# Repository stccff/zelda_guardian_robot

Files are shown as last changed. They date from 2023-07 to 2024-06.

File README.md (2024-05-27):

# 塞尔达传说旷野之息守护者模型项目

## 项目介绍

本项目致力于复刻《塞尔达传说：旷野之息》中的守护者模型。项目包含了守护者的SolidWorks模型、硬件PCB设计以及基于ESP32-S3的软件部分。

## 项目展示

- **图片**
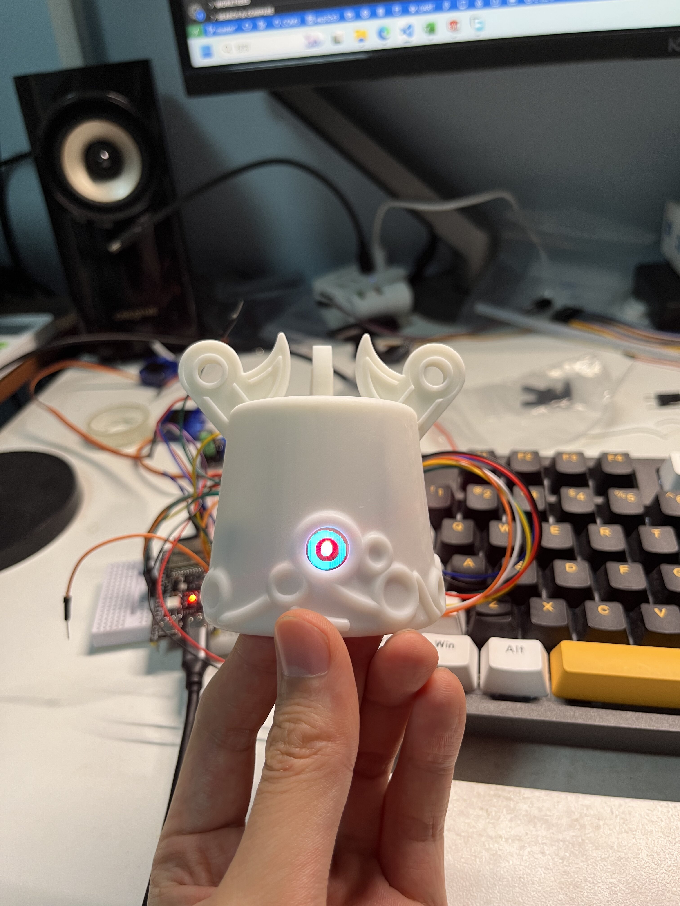
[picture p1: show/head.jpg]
头部测试
  - 
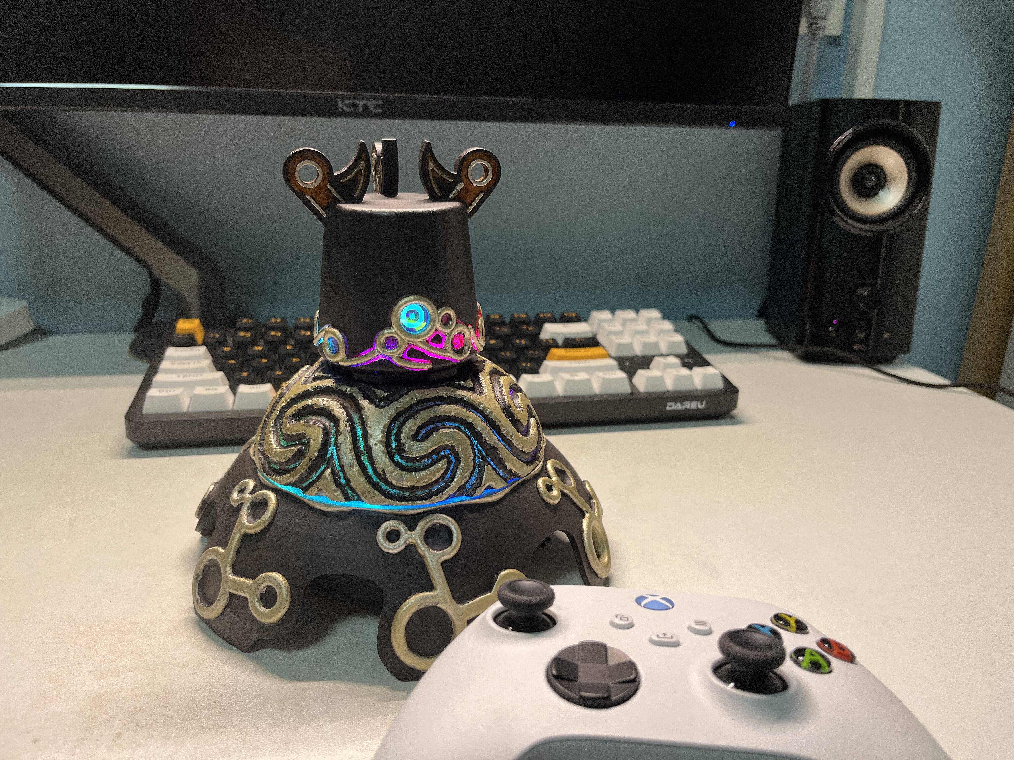
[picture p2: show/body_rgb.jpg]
RGB效果
  - 
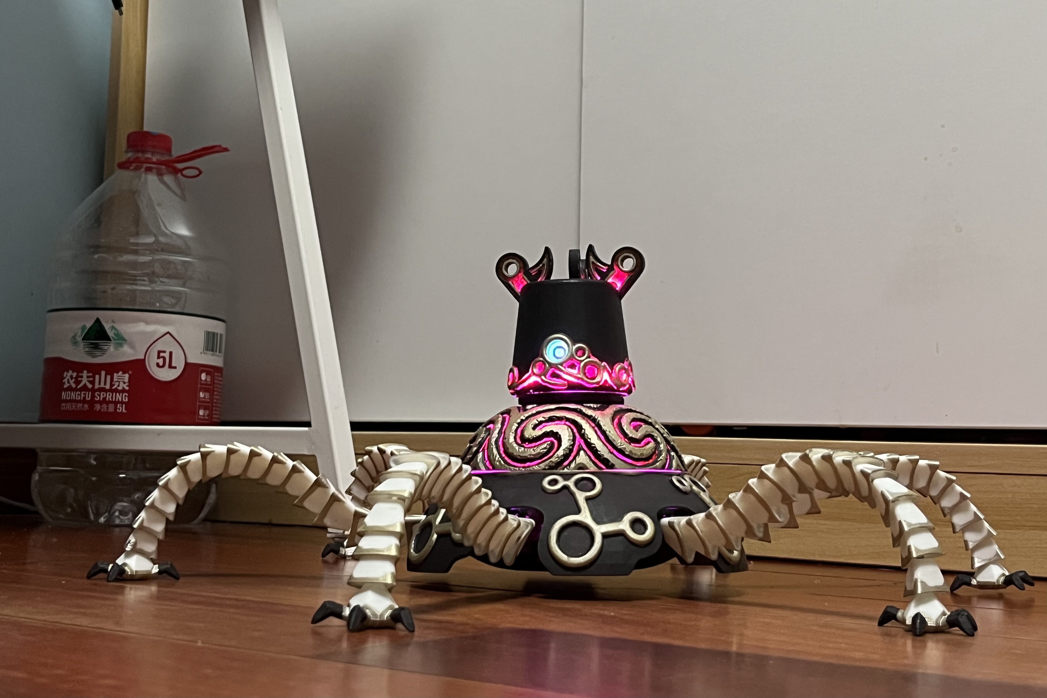
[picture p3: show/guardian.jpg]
整体效果
  - 
- **视频**
  - B站链接：https://www.bilibili.com/video/BV1vh4y1A7ve/?share_source=copy_web&vd_source=ff8870a89e973cca407edad87d57f622
  - 油管链接：https://youtu.be/EcbjQE96Pl4?si=KqaRee9nlnVQqD4i

## 项目内容

- **SolidWorks模型**
  - 守护者3D模型设计
  - 可打印的STL文件
- **硬件PCB设计**
  - 电路图和PCB布局
  - 元件清单
  - 制造文件
- **软件部分（ESP32-S3）**
  - 嵌入式C代码
  - 功能实现说明

## 使用说明

1. **获取SolidWorks模型**
   - 下载STL文件
   - 使用3D打印机打印模型
2. **硬件PCB制作**
   - 根据提供的文件制作PCB
   - 元件焊接与测试
3. **软件编程与调试**
   - 下载vs code或其他兼容的开发环境
   - 编译并上传固件到ESP32-S3模块
   - 调试与功能测试

## 开发环境

- **SolidWorks** (用于编辑和查看3D模型)
- **VS code** (用于编写和上传ESP32-S3代码)
- **推荐的PCB设计软件** (立创eda)

## 参与贡献

欢迎对《塞尔达传说：旷野之息》守护者模型感兴趣的开发者参与项目！请通过GitHub的Pull Request功能提交您的贡献。
也可以加入我的qq交流群：971609269

## 许可证

本项目采用[MIT许可证](https://opensource.org/licenses/MIT)。

## 联系方式

如需报告问题或提出建议，请通过GitHub的Issue跟踪系统告知。

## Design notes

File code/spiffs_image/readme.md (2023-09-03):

注意事项：
使用AU导出音频时，不能勾选"包含标记和其他元素"

guardian_beamsightlocking
	loop start: 5936 samples (0:00.124 seconds)
	loop end: 17498 samples (0:00.365 seconds)

guardian_beamsightsearch
	loop start: 0 samples (0:00.000 seconds)
	loop end: 5115 samples (0:00.107 seconds)

SE_Guardian_ActiveFastLoop
	loop start: 23100 samples (0:00.481 seconds)
	loop end: 116618 samples (0:02.430 seconds)

SE_Guardian_SlideLoop
	loop start: 31206 samples (0:00.650 seconds)
	loop end: 96924 samples (0:02.019 seconds)

Guardian_Active_Move
	loop start: 0 samples (0:00.000 seconds)
	loop end: 246537 samples (0:05.136 seconds)

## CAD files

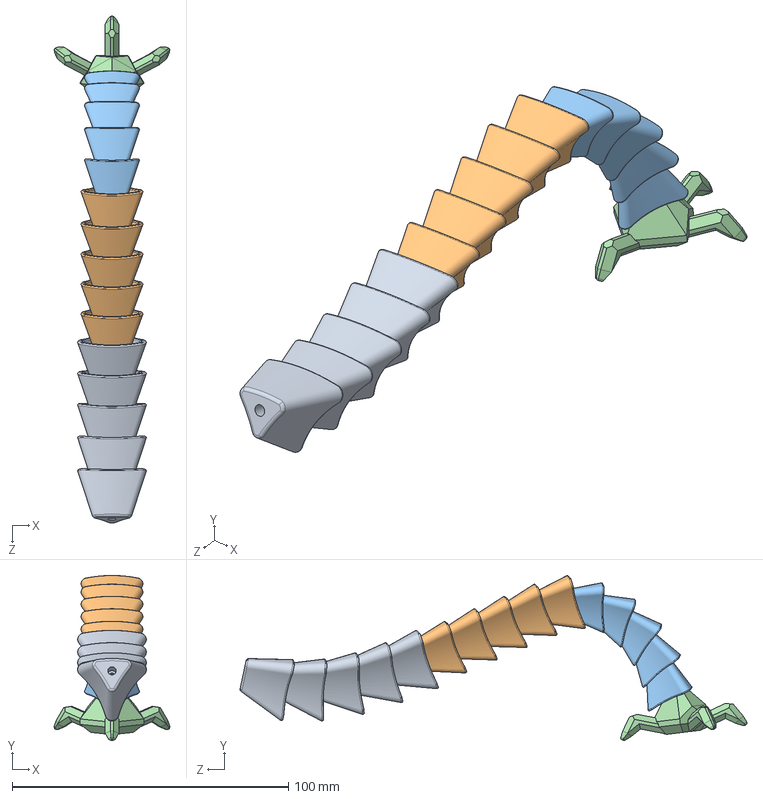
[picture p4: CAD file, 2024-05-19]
model/leg.SLDASM
41.9 x 59.8 x 183.7 mm
leg0 x 5
leg1 x 5
leg2 x 5
foot

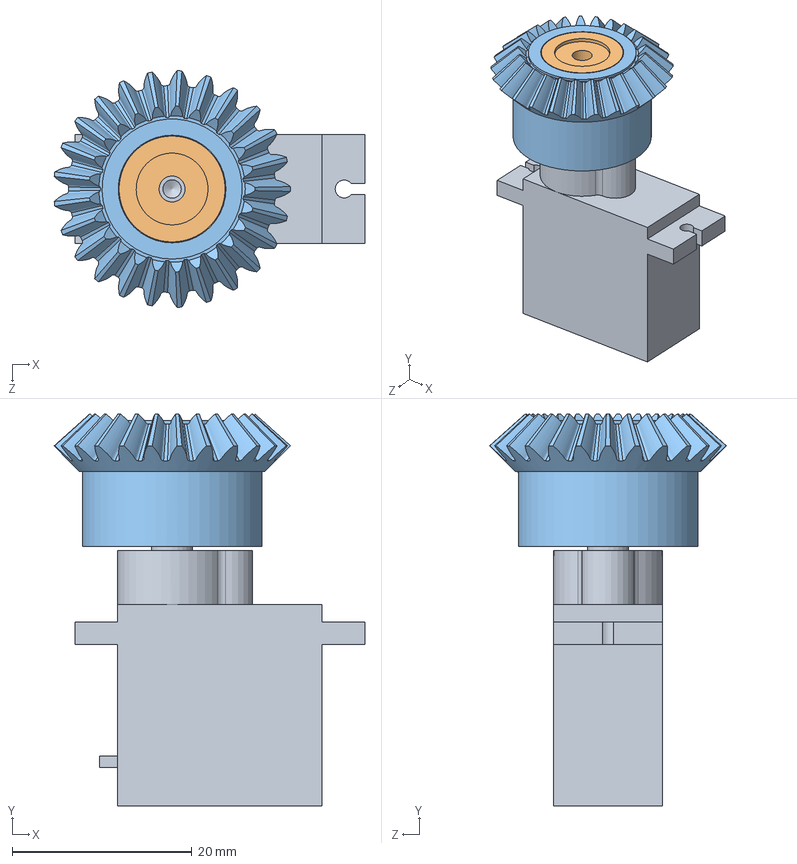
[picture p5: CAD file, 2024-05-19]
model/servo&gear.SLDASM
34.6 x 43.7 x 26.4 mm
servo_motor(MG90D)
servo&gear_connector
bevel_gear_25x1x12

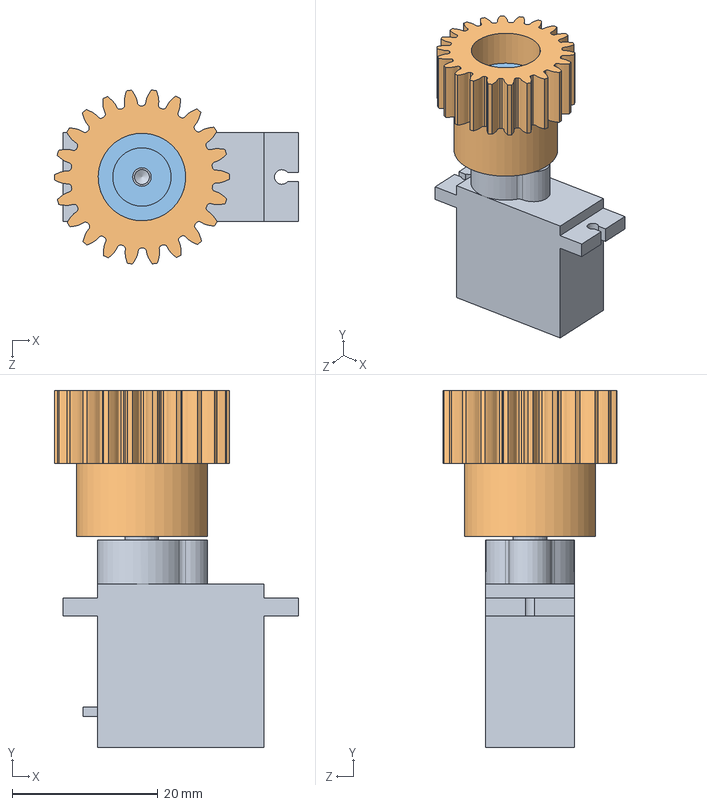
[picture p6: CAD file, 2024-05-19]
model/servo&gear2.SLDASM
33.5 x 48.9 x 23.9 mm
servo_motor(MG90D)
spur_gear_22x1_12
servo&gear_connector

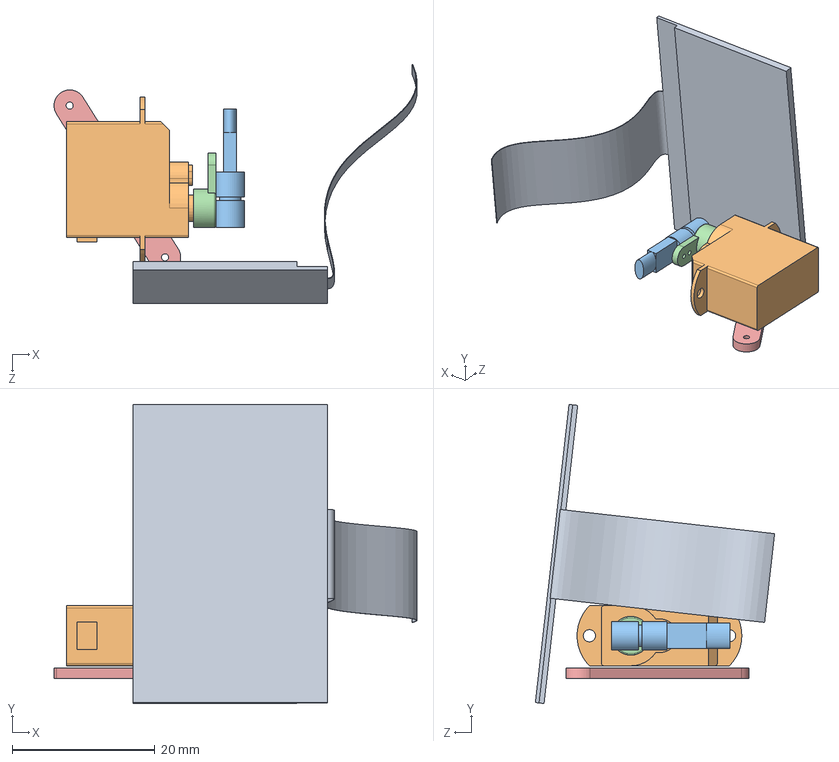
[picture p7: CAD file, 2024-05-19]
model/guardian_head.SLDASM
50.9 x 41.9 x 33.5 mm
oled_transparent
servo_motor(mini)
laser
mini_handle
servo_motor_holder2

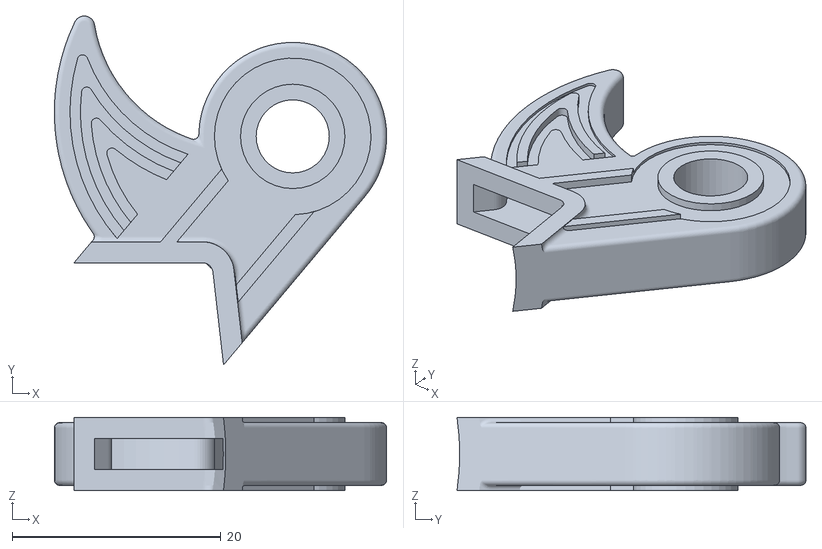
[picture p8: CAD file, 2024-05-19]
model/testchip/head_corner.STL
31.8 x 33.4 x 7.00

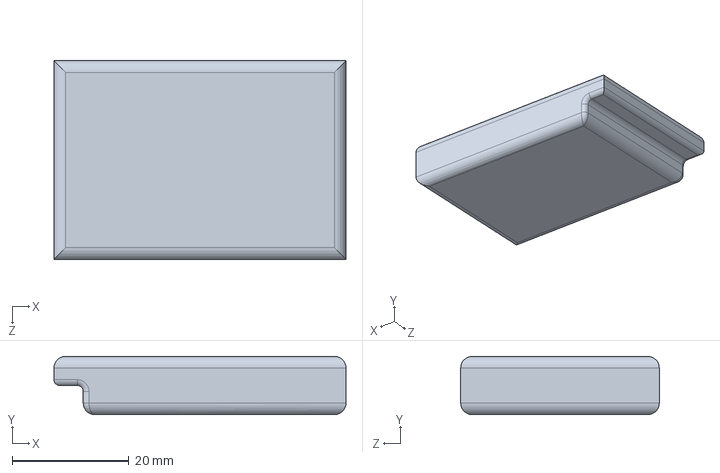
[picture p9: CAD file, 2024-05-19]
model/Li-ion_103450.SLDPRT
50.0 x 10.0 x 34.0 mm

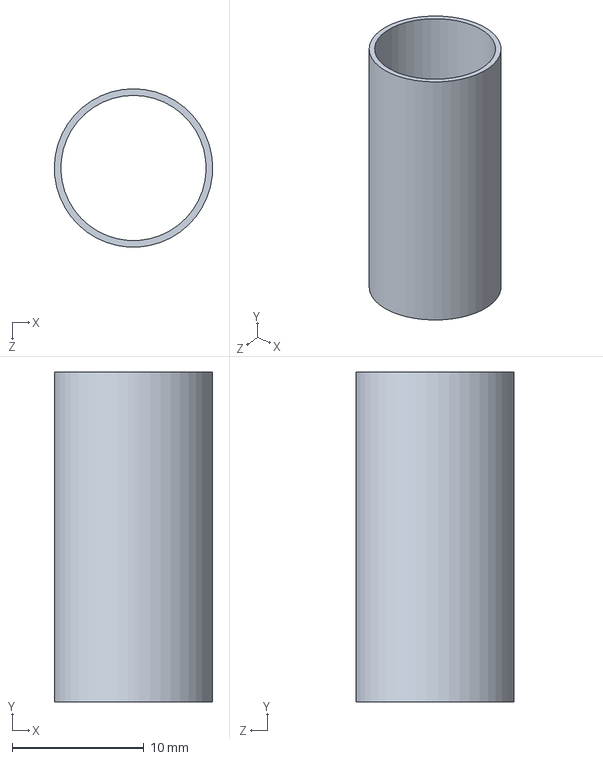
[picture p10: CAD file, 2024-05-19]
model/shaft_12x0.5.SLDPRT
12.0 x 25.0 x 12.0 mm

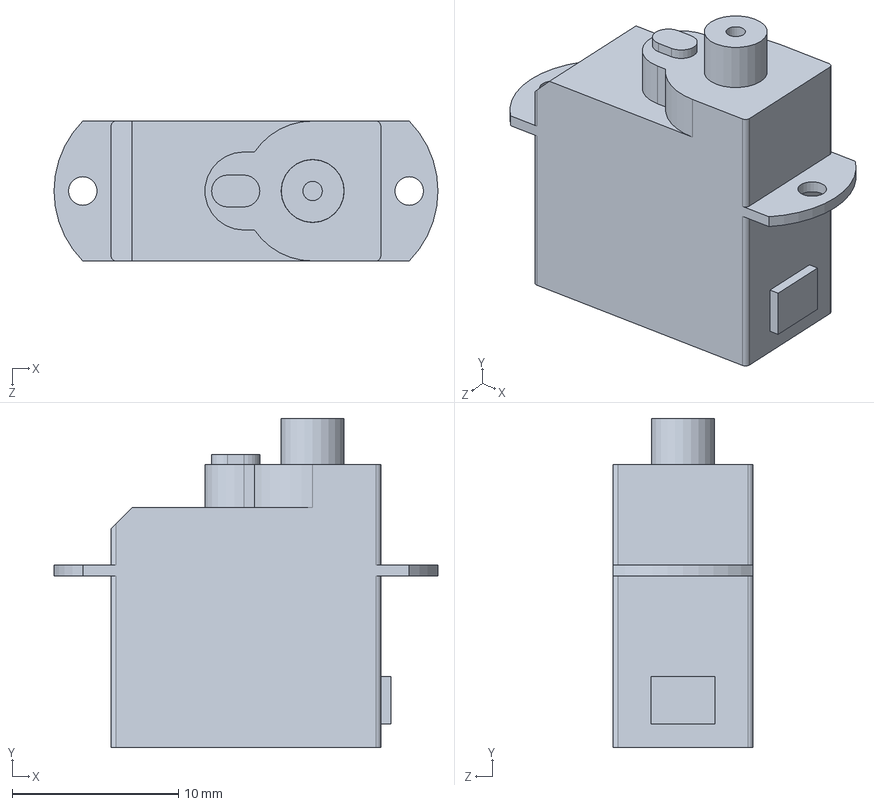
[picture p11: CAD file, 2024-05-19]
model/servo_motor(mini).SLDPRT
23.1 x 19.8 x 8.42 mm

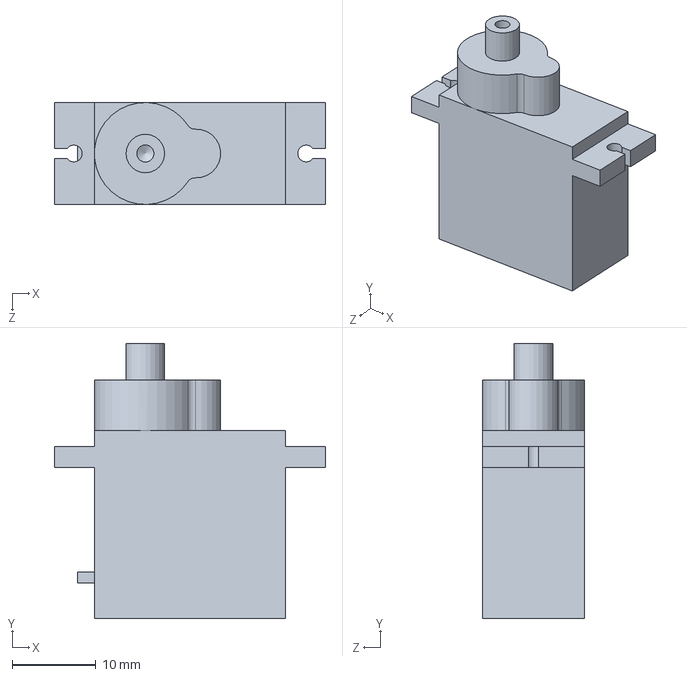
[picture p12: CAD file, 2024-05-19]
model/servo_motor(MG90D).SLDPRT
32.3 x 32.8 x 12.2 mm

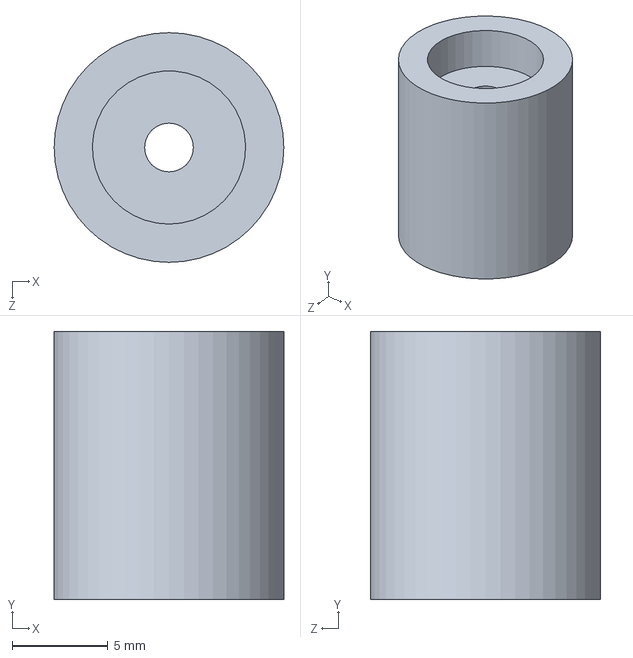
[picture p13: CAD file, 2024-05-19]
model/servo&gear_connector.SLDPRT
12.0 x 14.0 x 12.0 mm

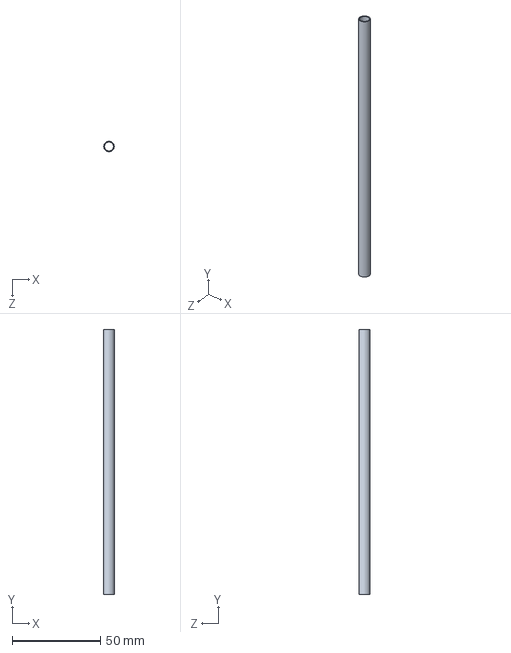
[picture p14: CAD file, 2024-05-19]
model/shaft_6x0.5.SLDPRT
6.00 x 150.0 x 6.00 mm

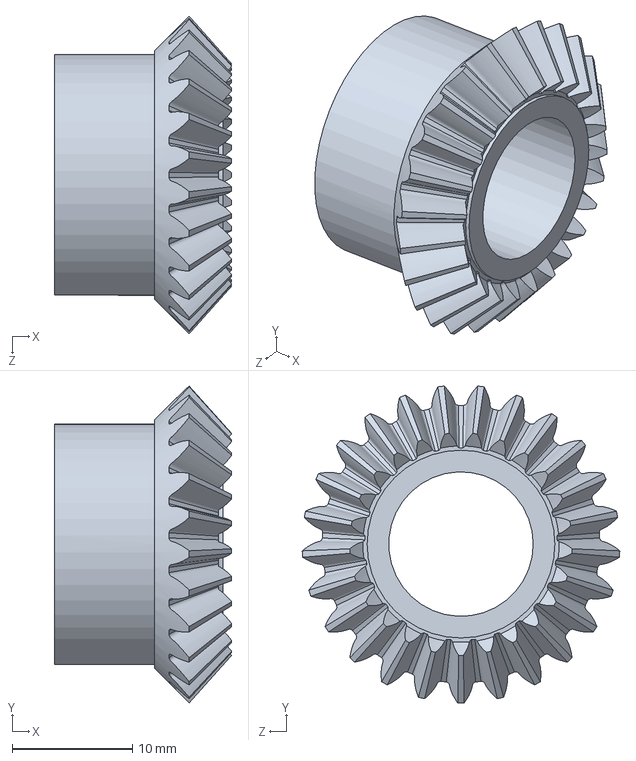
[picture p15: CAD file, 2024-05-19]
model/bevel_gear_25x1x12.SLDPRT
14.7 x 26.3 x 26.4 mm

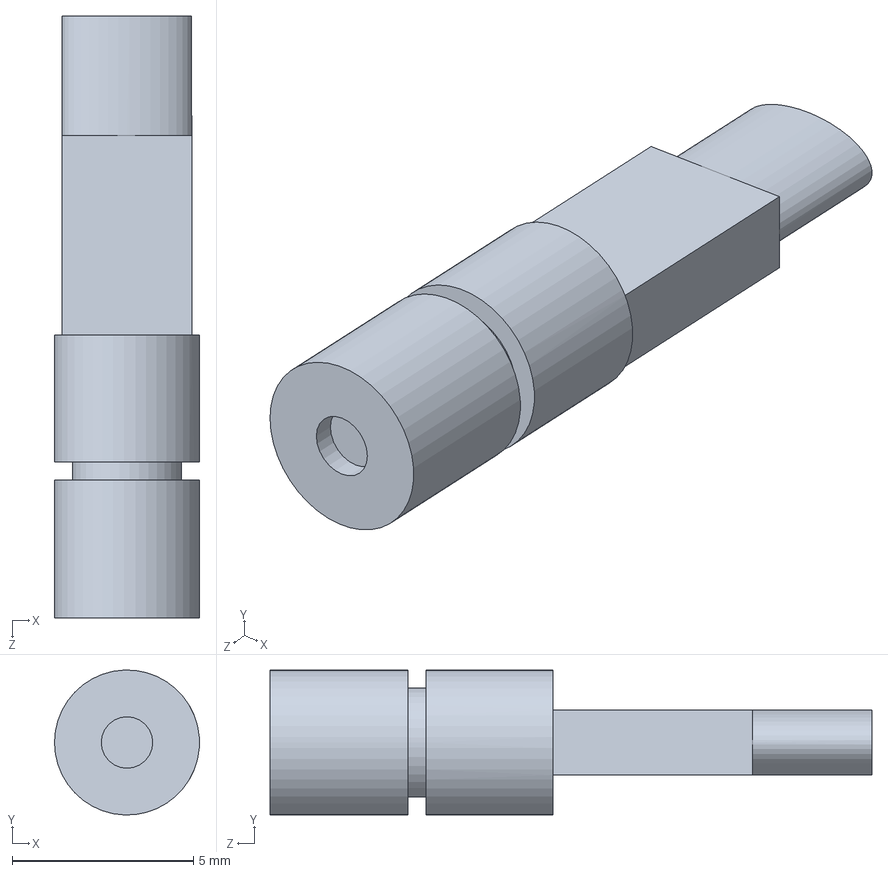
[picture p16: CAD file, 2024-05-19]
model/laser.SLDPRT
4.00 x 4.00 x 16.6 mm

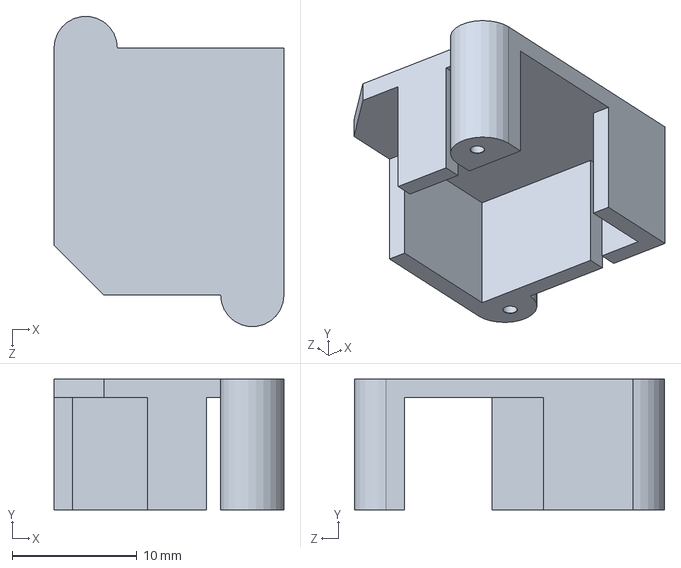
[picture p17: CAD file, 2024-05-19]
model/servo_motor_holder.SLDPRT
18.4 x 10.5 x 24.9 mm

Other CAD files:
model/bottom.SLDPRT
model/foot.SLDPRT
model/oled_transparent.SLDPRT
model/decorative_gear.SLDPRT
model/18650_with_protector.SLDPRT
model/bevel_gear_25x1x6.SLDPRT
model/bevel_gear_25x1x8.SLDPRT
model/head_connector.SLDPRT
model/legacy/handle2(MG90D).SLDPRT
model/legacy/spur_gear_20×1.SLDPRT
model/mini_handle.SLDPRT
model/servo_motor(SG90).SLDPRT
model/servo_motor_holder2.SLDPRT
model/shaft_10x0.8(2).SLDPRT
model/shaft_10x0.8.SLDPRT
model/shaft_12x0.5(2).SLDPRT
model/shaft_8x0.5.SLDPRT
model/speaker.SLDPRT
model/spur_gear_22x1_10.1.SLDPRT
model/spur_gear_22x1_12.SLDPRT

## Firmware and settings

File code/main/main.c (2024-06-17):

/*
 * SPDX-FileCopyrightText: 2021 Espressif Systems (Shanghai) CO LTD
 *
 * SPDX-License-Identifier: Unlicense OR CC0-1.0
 */

#include <stdio.h>
#include <stdlib.h>
#include <string.h>
#include "freertos/FreeRTOS.h"
#include "freertos/task.h"
#include "freertos/event_groups.h"
#include "esp_system.h"
#include "esp_log.h"
#include "hid_host_gamepad.h"
#include "oled_main.h"
#include "servo_control.h"
#include "i2s_std_sound.h"
#include "pwr_ctrl.h"
#include "rgb_ctrl.h"
#include "status_machine.h"

static portMUX_TYPE g_spinLock = portMUX_INITIALIZER_UNLOCKED;

/*
 vTaskGetRunTimeStats() 使用
 注意:
 使用 vTaskGetRunTimeStats() 前需使能:
 make menuconfig -> Component config -> FreeRTOS -> configUSE_TRACE_FACILITY
 make menuconfig -> Component config -> FreeRTOS -> Enable FreeRTOS trace facility -> configUSE_STATS_FORMATTING_FUNCTIONS
 make menuconfig -> Component config -> FreeRTOS -> Enable display of xCorelD in vlaskList
 make menuconfig -> Component config -> FreeRTOS -> configGENERATE_RUN_TIME_STATS
 通过上面配置，等同于使能 FreeRTOSConfig.h 中如下三个宏:
 configGENERATE_RUN_TIME_STATS，configUSE_STATS_FORMATTING_FUNCTIONS 和 configSUPPORT_DYNAMIC_ALLOCATION
 */
void print_task_info(char *buff)
{
    /* 打印当前任务列表 */
    vTaskList(buff);
    printf("task\t\tstate\tprio\tstack\ttid\tcore\n");
    printf("%s\n", buff);
    /* 打印任务运行信息 */
    vTaskGetRunTimeStats(buff);
    printf("task_name\trun_cnt\t\tusage\n");
    printf("%s\n", buff);
}

static bool is_demo_mod(void)
{
    volatile const struct XboxData *xbox = get_xbox_pad_data();
    if (sm_get_active_mod() != SM_DEMO || xbox->bnt2.btnStart == 1) {
        vTaskDelay(200 / portTICK_PERIOD_MS);
        sm_set_active_mod(SM_NORMAL);
        struct XboxData virXbox = {
            .joyLx = 0xffff / 2,
            .joyRx = 0xffff / 2,
            .joyRy = 0xffff / 2,
            .trigRT = 0,
        };
        set_xbox_pad_data_virtual(&virXbox);
        oled_set_display(OLED_OFF);
        vTaskDelay(200 / portTICK_PERIOD_MS);
        return false;
    }
    return true;
}

static bool demo_delay_and_check(uint32_t ms)
{
    bool is_demo;
    for (uint32_t i = 0; (i < ms / 20) && (is_demo = is_demo_mod() == true); i++) {
        vTaskDelay(20 / portTICK_PERIOD_MS);
    }

    return is_demo;
}

/**
 * @brief demo sequence
 * 
 */
static void do_demo_sequence(void)
{
    /* sleep */
    sm_set_light_status(SM_NO_LIGHT);
    if (demo_delay_and_check(4000) == false) {
        return;
    }
    
    /* eye on */
    oled_set_display(OLED_CIRCLE);
    sm_set_light_status(SM_LIGHT_SCREEN);
    sound_play_eyeon(true);
    if (demo_delay_and_check(3000) == false) {
        return;
    }

    /* blue */
    sm_set_light_status(SM_LIGHT_SCREEN_BLUE);
    if (demo_delay_and_check(3000) == false) {
        return;
    }

    /* randon move */
    struct XboxData virXbox = {
        .joyLx = 0xffff / 2,
        .joyRx = 0xffff / 2,
        .joyRy = 0xffff / 2,
        .trigRT = 0,
    };
    virXbox.joyLx = XBOX_JOYSTICK_MAX / 2 - XBOX_JOYSTICK_MAX / 20 * 9;
    virXbox.joyRx = XBOX_JOYSTICK_MAX / 2 + XBOX_JOYSTICK_MAX / 20 * 9;
    set_xbox_pad_data_virtual(&virXbox);
    if (demo_delay_and_check(500) == false) {
        return;
    }

    virXbox.joyLx = XBOX_JOYSTICK_MAX / 2 + XBOX_JOYSTICK_MAX / 20 * 9;
    virXbox.joyRx = XBOX_JOYSTICK_MAX / 2 - XBOX_JOYSTICK_MAX / 20 * 9;
    set_xbox_pad_data_virtual(&virXbox);
    if (demo_delay_and_check(1000) == false) {
        return;
    }

    virXbox.joyLx = XBOX_JOYSTICK_MAX / 2 - XBOX_JOYSTICK_MAX / 20 * 9;
    virXbox.joyRx = XBOX_JOYSTICK_MAX / 2 + XBOX_JOYSTICK_MAX / 20 * 9;
    set_xbox_pad_data_virtual(&virXbox);
    if (demo_delay_and_check(1000) == false) {
        return;
    }

    virXbox.joyLx = XBOX_JOYSTICK_MAX / 2 + XBOX_JOYSTICK_MAX / 20 * 9;
    virXbox.joyRx = XBOX_JOYSTICK_MAX / 2 - XBOX_JOYSTICK_MAX / 20 * 9;
    set_xbox_pad_data_virtual(&virXbox);
    if (demo_delay_and_check(500) == false) {
        return;
    }
    
    // resume
    virXbox.joyLx = XBOX_JOYSTICK_MAX / 2;
    virXbox.joyRx = XBOX_JOYSTICK_MAX / 2;
    set_xbox_pad_data_virtual(&virXbox);

    /* attach */
    sm_set_light_status(SM_LIGHT_SCREEN_RED);
    if (demo_delay_and_check(1000) == false) {
        return;
    }
    virXbox.trigRT = XBOX_TRIGGER_MAX;
    set_xbox_pad_data_virtual(&virXbox);

    virXbox.joyRy = XBOX_JOYSTICK_MAX / 2 - XBOX_JOYSTICK_MAX / 20 * 6;
    set_xbox_pad_data_virtual(&virXbox);
    if (demo_delay_and_check(200) == false) {
        return;
    }

    virXbox.joyRy = XBOX_JOYSTICK_MAX / 2 + XBOX_JOYSTICK_MAX / 20 * 6;
    set_xbox_pad_data_virtual(&virXbox);
    if (demo_delay_and_check(400) == false) {
        return;
    }

    virXbox.joyRy = XBOX_JOYSTICK_MAX / 2 - XBOX_JOYSTICK_MAX / 20 * 6;
    set_xbox_pad_data_virtual(&virXbox);
    if (demo_delay_and_check(400) == false) {
        return;
    }

    virXbox.joyRy = XBOX_JOYSTICK_MAX / 2 + XBOX_JOYSTICK_MAX / 20 * 6;
    set_xbox_pad_data_virtual(&virXbox);
    if (demo_delay_and_check(400) == false) {
        return;
    }

    virXbox.joyRy = XBOX_JOYSTICK_MAX / 2 - XBOX_JOYSTICK_MAX / 20 * 6;
    set_xbox_pad_data_virtual(&virXbox);
    if (demo_delay_and_check(200) == false) {
        return;
    }

    // resume
    virXbox.joyRy = XBOX_JOYSTICK_MAX / 2;
    set_xbox_pad_data_virtual(&virXbox);

    if (demo_delay_and_check(4000) == false) {
        return;
    }
    
    virXbox.trigRT = 0;
    set_xbox_pad_data_virtual(&virXbox);
    if (demo_delay_and_check(5000) == false) {
        return;
    }

    sm_set_light_status(SM_LIGHT_SCREEN_BLUE);
    if (demo_delay_and_check(10000) == false) {
        return;
    }
}

/**
 * @brief 主函数
 * 
 */
void app_main(void)
{
    /* init process*/
    taskENTER_CRITICAL(&g_spinLock);
    status_machine_init();
    taskEXIT_CRITICAL(&g_spinLock);

    pwr_ctrl_init();    // 2
    servo_init();       // 3
    sound_init();       // 7/6
    oled_main();        // 10   周期刷新数据
    argb_init();        // 12   周期刷新数据
    hid_host_init();    // 15

    char *buff = (char *)malloc(1024);
    print_task_info(buff);

    while (1) {
        /* print task info */
        volatile const struct XboxData *xbox = get_xbox_pad_data();
        if (xbox->bnt3.share == 1) {
            print_task_info(buff);
        }

        /* demo mod detecte */
        if (xbox->bnt2.btnStart == 1) {
            vTaskDelay(300 / portTICK_PERIOD_MS);
            sm_set_active_mod(SM_DEMO);
        }

        /* demo auto play */
        while (sm_get_active_mod() == SM_DEMO) {
            do_demo_sequence();
        }

        vTaskDelay(100 / portTICK_PERIOD_MS);
    }
    free(buff);

    vTaskDelete(NULL);
}

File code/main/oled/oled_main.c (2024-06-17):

/* SPI Master example

   This example code is in the Public Domain (or CC0 licensed, at your option.)

   Unless required by applicable law or agreed to in writing, this
   software is distributed on an "AS IS" BASIS, WITHOUT WARRANTIES OR
   CONDITIONS OF ANY KIND, either express or implied.
*/
#include <stdio.h>
#include <stdlib.h>
#include <string.h>
#include <inttypes.h>
#include "freertos/FreeRTOS.h"
#include "freertos/task.h"
#include "esp_system.h"
#include "driver/spi_master.h"
#include "driver/gpio.h"
#include "oled_drv.h"
#include "driver/uart.h"
#include "picture.h"
#include <math.h>
#include "oled_main.h"
#include "status_machine.h"
#include "esp_log.h"
#include "pwr_ctrl.h"
#include "i2s_std_sound.h"
#include "common_func.h"

/* 宏定义 */
#define TEST_TASK_STACK_SIZE    (10 * 1024)

#define SCREEN_WIDTH    (128)   // 屏幕长
#define SCREEN_HEIGHT   (64)    // 屏幕高
#define SCREEN_PAGE_NUM (8)     // 屏幕页数

#define CIRCLE_WIDTH    (48)    // 画圆的buffer长
#define CIRCLE_HEIGHT   (48)    // 画圆的buffer宽
#define CIRCLE_x        (21)    // 圆心在buff中的x坐标
#define CIRCLE_y        (24)    // 圆心在buff中的y坐标
#define MASK_R          (21)    // 外部遮罩半径

/* 结构体定义 */
struct OledMonoBuff {
    int width;
    int height;
    uint8_t *buff;  // buff指针
};

/* 全局变量 */
static const char *TAG = "OLED";



static double square(double x)
{
	return x * x;
}

/**
 * @brief 设置一个Byte中对应的bit像素点
 * 
 * @param pixel8 一个子节对应的8个像素
 * @param index 设置的像素索引
 * @param val 像素颜色（黑/白）
 */
static void set_bit(unsigned char *pixel8, int index, int val)
{
    if (val == 0) {
        *pixel8 &= ~((unsigned char)(1 << index));
    } else {
        *pixel8 |= (unsigned char)(1 << index);
    }
}

/**
 * @brief 设置一个绘制buff中的一个像素值
 * 
 * @param buff 屏幕buff结构体指针
 * @param row 设置的行数
 * @param col 设置的列数
 * @param val 像素颜色（黑/白）
 */
static void oled12864_set_pixel(struct OledMonoBuff *buff, int row, int col, int val)
{
    if ((row >= buff->height) || (col >= buff->width)) {
        return;
    }
    
    int page = col / 8;
    int index = col % 8;
    set_bit(&buff->buff[page * buff->width + row], index, val);
}

/**
 * @brief 绘制一个环形，存放在指定buff中
 * 
 * @param buff 屏幕buff结构体指针
 * @param x 圆心横坐标
 * @param y 圆心纵坐标
 * @param r1 内径
 * @param r2 外径
 * @param val 像素颜色（黑/白）
 */
static void draw_circle(struct OledMonoBuff *buff, int x, int y, int r1, int r2, int val)
{
    for (int i = 0; i < buff->height; i++) {
        for (int j = 0; j < buff->width; j++) {
			double len2 = square(i - x) + square(j - y);
            if ((len2 >= r1 * r1) && (len2 < r2 * r2) && (len2 <= MASK_R * MASK_R)) {
                oled12864_set_pixel(buff, i, j, val);
            }
        }
    }
}

/**
 * @brief 绘制多重环形图案，并写入指定的buff中
 * 
 * @param buff 屏幕buff结构体指针
 * @param outerR 最内部环形外径
 * @param width 环形宽度（内外径差）
 * @param interval 相邻环形半径
 * @param val 像素颜色（黑/白）
 */
static void draw_multi_circle(struct OledMonoBuff *buff, int outerR, int width, int interval, int val)
{
    // width = 6;
    double maxR = sqrt(buff->width * buff->width + buff->height * buff->height);    // 绘制圆的最大半径：使用对角线长度，填充整个buff
    while (outerR <= (maxR + width + 1)) {  // 绘制圆直至内径到buff边缘
        int innerR = (outerR - width) > 0 ? (outerR - width) : 0;
        int midX = CIRCLE_x;
        int midY = CIRCLE_y;
        draw_circle(buff, midX, midY, innerR, outerR, val);
        outerR += interval;
    }     
}

/**
 * @brief 创建多重圆环扩散帧（守护者眼部动画帧）
 * 
 * @param width 圆环宽度
 * @param interval 两个圆环间隔
 * @return struct OledMonoBuff* 
 */
static struct OledMonoBuff* create_multi_circle_frames(int width, int interval)
{
    int startR = 1;

    struct OledMonoBuff *buffs = (struct OledMonoBuff *)malloc(sizeof(struct OledMonoBuff) * interval);

    for (int i = 0; i < interval; i++) {
        buffs[i].width = CIRCLE_WIDTH;      // buff长
        buffs[i].height = CIRCLE_HEIGHT;    // buff高
        int size = CIRCLE_WIDTH * CIRCLE_HEIGHT / 8;    // 一帧的大小
        buffs[i].buff = (uint8_t *)malloc(size);
        memset(buffs[i].buff, 0, size);
        draw_multi_circle(&buffs[i], startR, width, interval, 1);
        startR++;
    }

    return buffs;
}



static void oled_task(void *arg)
{
    int interval = 12;
    struct OledMonoBuff *normalBuffs = create_multi_circle_frames(6, interval);
    ESP_ERROR_CHECK(normalBuffs == NULL);

    ESP_LOGI(TAG, "draw circle");


    while (1) {
        if (sm_get_light_status() <= SM_NO_LIGHT) {
            OLED_Display_Off();
            vTaskDelay(500 / portTICK_PERIOD_MS);
            continue;
        } else {
            OLED_Display_On();
        }

        switch (oled_get_display()) {
            case OLED_CIRCLE:
                for (int i = 0; i < interval; i++) {
                    OLED_DrawBMP(0, 2, 47, 7, normalBuffs[i].buff);
                    vTaskDelay(41 / portTICK_PERIOD_MS);
                }
                break;
            case OLED_BAT:
                OLED_Clear();
                float percent;
                int vol = get_bat_voltage(&percent);

                OLED_ShowChar90(20, 3, 'B');
                OLED_ShowChar90(20, 4, 'a');
                OLED_ShowChar90(20, 5, 't');
                OLED_ShowChar90(20, 6, ':');
                char vones = vol / 1000;
                char tenths = (vol / 100) % 10;
                char hundredths = (vol / 10) % 10;
                OLED_ShowChar90(4, 3, '0' + vones);
                OLED_ShowChar90(4, 4, '.');
                OLED_ShowChar90(4, 5, '0' + tenths);
                OLED_ShowChar90(4, 6, '0' + hundredths);
                vTaskDelay(1000 / portTICK_PERIOD_MS);
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

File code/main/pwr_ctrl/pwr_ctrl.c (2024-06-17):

/* GPIO Example

   This example code is in the Public Domain (or CC0 licensed, at your option.)

   Unless required by applicable law or agreed to in writing, this
   software is distributed on an "AS IS" BASIS, WITHOUT WARRANTIES OR
   CONDITIONS OF ANY KIND, either express or implied.
*/
#include <stdio.h>
#include <string.h>
#include <stdlib.h>
#include <inttypes.h>
#include "freertos/FreeRTOS.h"
#include "freertos/task.h"
#include "freertos/queue.h"
#include "driver/gpio.h"
#include "driver/gpio_filter.h"
#include "hid_host_gamepad.h"
#include "time.h"
#include "status_machine.h"

#include "soc/soc_caps.h"
#include "esp_log.h"
#include "esp_adc/adc_oneshot.h"
#include "esp_adc/adc_cali.h"
#include "esp_adc/adc_cali_scheme.h"
#include "common_func.h"
#include "pwr_ctrl.h"


const static char *TAG = "PWR_CTRL";

#define GPIO_PWR_CTRL   GPIO_NUM_9
#define GPIO_LASER_CTRL GPIO_NUM_37
#define GPIO_FUNC0      GPIO_NUM_46
#define TASK_PERIOD     (30)    // task周期（ms）
#define ESP_INTR_FLAG_DEFAULT 0
#define POWER_OFF_DELAY (60)    // s
#define ADC_SAMPLE_PERIOD (10)  // s
#define BAT_ADC1_CHN    ADC_CHANNEL_2

#define BAT_ADC 1


enum ClickState {
    NO_CLICK,
    WAIT_RASING,
    WAIT_CHECKED,
    SINGLE_CLICK,
    DOUBLE_CLICK,
    LONG_PRESS,
};

// 结构体定义
typedef struct {
    float vol;
    float percent;
} Vol2PerSt;

// 全局变量
static QueueHandle_t g_gpioEventQueue = NULL;

static adc_oneshot_unit_handle_t g_adc1_handle = NULL;
static adc_cali_handle_t g_adc1_cali_handle = NULL;
static bool g_do_calibration = false;
static int g_batVol;
static float g_batPer = 0;

// 松下3200mAh电池，参考数据手册600mA放电曲线
const static Vol2PerSt g_batTlbPanasonic[] = {
    {4.10, 1.00},
    {3.90, 0.84},
    {3.76, 0.68},
    {3.70, 0.60},
    {3.62, 0.52},
    {3.53, 0.35},
    {3.47, 0.26},
    {3.41, 0.19},
    {3.34, 0.13},
    {3.23, 0.06},
    {3.20, 0.05},
    {3.13, 0.03},
    {3.00, 0.01},
    {2.75, 0.00},
};

// 函数声明
static bool example_adc_calibration_init(adc_unit_t unit, adc_atten_t atten, adc_cali_handle_t *out_handle);
static void example_adc_calibration_deinit(adc_cali_handle_t handle);

/**
 * @brief 电池电压转换成百分比，公式：p = p0 + (v-v0)/(v1-v0)*(p1-p0)
 * 
 * @param tlb 电压-电量表
 * @param len 表长
 * @param vol 电压
 * @return float 百分比
 */
static float bat_vol_to_percent(const Vol2PerSt *tlb, uint32_t len, float vol)
{
    if (vol > tlb[0].vol) {
        return tlb[0].percent;
    }

    for (uint32_t i = 0; i < len - 1; i++) {
        if ((vol <= tlb[i].vol) && (vol > tlb[i + 1].vol)) {
            return tlb[i].percent + (vol - tlb[i].vol) / (tlb[i + 1].vol - tlb[i].vol) * (tlb[i + 1].percent - tlb[i].percent);
        }
    }

    return tlb[len - 1].percent;
}

/**
 * @brief Get the bat voltage object
 * 
 * @param[out] percent 电压百分比
 * @return int 电压（mV）
 */
int get_bat_voltage(float *percent)
{
    *percent = g_batPer;
    return g_batVol;
}

/**
 * @brief adc处理程序
 * 
 * @param cnt 任务计数
 */
void adc_ctrl(uint32_t cnt)
{
    if ((cnt % ((ADC_SAMPLE_PERIOD * 1000) / TASK_PERIOD)) == 0) {
        int adc_raw = 0;
        ESP_ERROR_CHECK(adc_oneshot_read(g_adc1_handle, BAT_ADC1_CHN, &adc_raw));
        // ESP_LOGI(TAG, "ADC%d Channel[%d] Raw Data: %d", ADC_UNIT_1 + 1, BAT_ADC1_CHN, adc_raw);
        if (g_do_calibration) {
            int voltage = 0;
            ESP_ERROR_CHECK(adc_cali_raw_to_voltage(g_adc1_cali_handle, adc_raw, &voltage));
            g_batVol = voltage * 2;
            g_batPer = bat_vol_to_percent(g_batTlbPanasonic, sizeof(g_batTlbPanasonic) / sizeof(Vol2PerSt), (float)g_batVol / 1000);
            ESP_LOGI(TAG, "Battary Voltage: %dmV, %.2f%%", g_batVol, g_batPer * 100);
        }
    }

    // Tear Down
    // ESP_ERROR_CHECK(adc_oneshot_del_unit(g_adc1_handle));
    // if (g_do_calibration) {
    //     example_adc_calibration_deinit(g_adc1_cali_handle);
    // }
}

/*---------------------------------------------------------------
        ADC Calibration
---------------------------------------------------------------*/
static bool example_adc_calibration_init(adc_unit_t unit, adc_atten_t atten, adc_cali_handle_t *out_handle)
{
    adc_cali_handle_t handle = NULL;
    esp_err_t ret = ESP_FAIL;
    bool calibrated = false;

    if (!calibrated) {
        ESP_LOGI(TAG, "calibration scheme version is %s", "Curve Fitting");
        adc_cali_curve_fitting_config_t cali_config = {
            .unit_id = unit,
            .atten = atten,
            .bitwidth = ADC_BITWIDTH_DEFAULT,
        };
        ret = adc_cali_create_scheme_curve_fitting(&cali_config, &handle);
        if (ret == ESP_OK) {
            calibrated = true;
        }
    }

    *out_handle = handle;
    if (ret == ESP_OK) {
        ESP_LOGI(TAG, "Calibration Success");
    } else if (ret == ESP_ERR_NOT_SUPPORTED || !calibrated) {
        ESP_LOGW(TAG, "eFuse not burnt, skip software calibration");
    } else {
        ESP_LOGE(TAG, "Invalid arg or no memory");
    }

    return calibrated;
}

static void example_adc_calibration_deinit(adc_cali_handle_t handle)
{
    ESP_LOGI(TAG, "deregister %s calibration scheme", "Curve Fitting");
    ESP_ERROR_CHECK(adc_cali_delete_scheme_curve_fitting(handle));
}


/**
 * @brief gpio中断处理函数
 * 
 * @param arg 
 */
static void IRAM_ATTR gpio_isr_handler(void* arg)
{
    uint64_t time = DRV_GetTime();
    xQueueSendFromISR(g_gpioEventQueue, &time, NULL);
}

/**
 * @brief 激光打光控制
 * 
 */
static void laser_ctrl(void)
{
    const struct XboxData *xbox = get_xbox_pad_data();
    uint32_t level;
    if ((xbox->trigRT > (XBOX_TRIGGER_MAX / 2)) || (xbox->trigLT > (XBOX_TRIGGER_MAX / 2))) {
        level = 1;
    } else {
        level = 0;
    }
    gpio_set_level(GPIO_LASER_CTRL, level);
}

/**
 * @brief 模拟单击操作
 * 
 */
static void single_click_simulation(void)
{
    gpio_set_level(GPIO_PWR_CTRL, 0);
    vTaskDelay(100 / portTICK_PERIOD_MS);
    gpio_set_level(GPIO_PWR_CTRL, 1);
}


static void try_power_off(void)
{
    ESP_LOGI(TAG, "try to power off!");
    single_click_simulation();
    vTaskDelay(500 / portTICK_PERIOD_MS);
    single_click_simulation();
    ESP_LOGE(TAG, "power off fail!!!");
}

/**
 * @brief 检查是否触发关机
 * 
 */
static void check_power_off(void)
{
    volatile const struct XboxData *xbox = get_xbox_pad_data();
    enum LightStatus status = sm_get_light_status();   // 获取灯光状态
    static enum LightStatus lastStatus = SM_LIGHT_NUN;
    static uint64_t pwrOffTime = 0;

    if (xbox->bnt2.btnSel == 1) {
        try_power_off();
    } 
    if (status == SM_NO_LIGHT) {
        if (lastStatus != status) {
            pwrOffTime = POWER_OFF_DELAY + DRV_GetTime() / 1000000; // 秒
        }
        if (DRV_GetTime() / 1000000 == pwrOffTime) {
            try_power_off();
        }   
    }

    lastStatus = status;
}
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

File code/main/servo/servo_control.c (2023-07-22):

/*
 * SPDX-FileCopyrightText: 2022 Espressif Systems (Shanghai) CO LTD
 *
 * SPDX-License-Identifier: Apache-2.0
 */

#include "freertos/FreeRTOS.h"
#include "freertos/task.h"
#include "esp_log.h"
#include "driver/mcpwm_prelude.h"
#include "servo_control.h"
#include "hid_host_gamepad.h"
#include <math.h>
#include "driver/gpio.h"
#include <string.h>

// #define MIN(a, b)   ((a < b) ? a : b)
// #define MAX(a, b)   ((a > b) ? a : b)

#define SERVO_TIMEBASE_RESOLUTION_HZ 1000000 // 1MHz, 1us per tick
#define SERVO_TIMEBASE_PERIOD 20000          // 20000 ticks, 20ms

#define PWM_GROUP   (1)

// 舵机
#define SERVO_NUMS (3)
#define SERVO_STOP_TIMEOUT (1000)   // ms

// 摇杆
#define JOY_MID_VAL (XBOX_JOYSTICK_MAX / 2)
#define JOY_DEAD_ZONE (0.10)
#define SERVO_MAX_SPEED (60.0 / 300.0) // usually 200ms/60degree
#define PROCESS_PERIOD (10)            // 50ms

/* 结构体定义 */
typedef struct
{
    int pulseWidthUsMin;    // 硬件脉宽规格
    int pulseWidthUsMax;
    int angleSpecMIn;       // 硬件角度旋转范围
    int angleSpecMax;
    int angleLimitMin;      // 角度限制（软件配置）
    int angleLimitMax;
    int initAngle;          // 初始状态角度
    int gpioPin;            // gpio引脚
} ServoMotorCfgItemSt;

typedef struct
{   
    /* 配置信息 */
    const ServoMotorCfgItemSt cfg;
    /* 运行态信息 */
    mcpwm_cmpr_handle_t cmp;
    mcpwm_timer_handle_t timer;
    double currentAngle;
    uint64_t stopTimer;
    bool status;
} ServoMotorObjSt;

/* 全局变量 */
static const char *TAG = "servo";
static ServoMotorObjSt g_servo[SERVO_NUMS] = {
    {   /* 头部转动舵机 x轴 */
        .cfg = {
            .pulseWidthUsMin = 500,
            .pulseWidthUsMax = 2500,
            .angleSpecMIn = -90,
            .angleSpecMax = 90,
            .angleLimitMin = -90,
            .angleLimitMax = 90,
            .initAngle = 0,
            .gpioPin = GPIO_NUM_11,
        },
        .currentAngle = 0,
        .stopTimer = 0,
        .status = false,
    },
    {   /* 眼部激光舵机 y轴 */
        .cfg = {
            .pulseWidthUsMin = 500,
            .pulseWidthUsMax = 2500,
            .angleSpecMIn = -90,
            .angleSpecMax = 90,
            .angleLimitMin = -17,   // 上
            .angleLimitMax = 18,    // 下
            .initAngle = 0,
            .gpioPin = GPIO_NUM_12,
        },
        .currentAngle = 0,
        .stopTimer = 0,
        .status = false,
    },
    {   /* 肩部圆环舵机 */
        .cfg = {
            .pulseWidthUsMin = 500,
            .pulseWidthUsMax = 2500,
            .angleSpecMIn = -135,
            .angleSpecMax = 135,
            .angleLimitMin = -135,
            .angleLimitMax = 135,
            .initAngle = 0,
            .gpioPin = GPIO_NUM_10,
        },
        .currentAngle = 0,
        .stopTimer = 0,
        .status = false,
    },
};

/**
 * @brief 角度换算成比较器的值
 *
 * @param angle 角度
 * @return uint32_t 比较器值
 */
static uint32_t angle_to_compare(const ServoMotorCfgItemSt *cfg, double angle)
{
    return (angle - cfg->angleSpecMIn) / (cfg->angleSpecMax - cfg->angleSpecMIn) *
           (cfg->pulseWidthUsMax - cfg->pulseWidthUsMin) + cfg->pulseWidthUsMin;
}

/**
 * @brief 创建一个pwm发生器
 *
 * @param groupId 定时器/操作器id
 * @param gpioNum gpio管脚
 * @return mcpwm_cmpr_handle_t 比较器handler
 */
static mcpwm_cmpr_handle_t create_pwm_gen(int groupId, ServoMotorObjSt *servoObj)
{
    ESP_LOGI(TAG, "Create timer and operator");
    // mcpwm_timer_handle_t timer = NULL;
    mcpwm_timer_config_t timer_config = {
        .group_id = groupId,
        .clk_src = MCPWM_TIMER_CLK_SRC_DEFAULT,
        .resolution_hz = SERVO_TIMEBASE_RESOLUTION_HZ,
        .period_ticks = SERVO_TIMEBASE_PERIOD,
        .count_mode = MCPWM_TIMER_COUNT_MODE_UP,
    };
    ESP_ERROR_CHECK(mcpwm_new_timer(&timer_config, &servoObj->timer));

    mcpwm_oper_handle_t oper = NULL;
    mcpwm_operator_config_t operator_config = {
        .group_id = groupId, // operator must be in the same group to the timer
    };
    ESP_ERROR_CHECK(mcpwm_new_operator(&operator_config, &oper));

    ESP_LOGI(TAG, "Connect timer and operator");
    ESP_ERROR_CHECK(mcpwm_operator_connect_timer(oper, servoObj->timer));

    ESP_LOGI(TAG, "Create comparator and generator from the operator");
    mcpwm_cmpr_handle_t comparator = NULL;
    mcpwm_comparator_config_t comparator_config = {
        .flags.update_cmp_on_tez = true,
    };
    ESP_ERROR_CHECK(mcpwm_new_comparator(oper, &comparator_config, &comparator));

    mcpwm_gen_handle_t generator = NULL;
    mcpwm_generator_config_t generator_config = {
        .gen_gpio_num = servoObj->cfg.gpioPin, // GPIO connects to the PWM signal line
    };
    ESP_ERROR_CHECK(mcpwm_new_generator(oper, &generator_config, &generator));

    // set the initial compare value, so that the servo will spin to the center position
    ESP_ERROR_CHECK(mcpwm_comparator_set_compare_value(comparator, angle_to_compare(&servoObj->cfg, servoObj->cfg.initAngle)));

    ESP_LOGI(TAG, "Set generator action on timer and compare event");
    // go high on counter empty
    ESP_ERROR_CHECK(mcpwm_generator_set_actions_on_timer_event(generator,
                                                               MCPWM_GEN_TIMER_EVENT_ACTION(MCPWM_TIMER_DIRECTION_UP, MCPWM_TIMER_EVENT_EMPTY, MCPWM_GEN_ACTION_HIGH),
                                                               MCPWM_GEN_TIMER_EVENT_ACTION_END()));
    // go low on compare threshold
    ESP_ERROR_CHECK(mcpwm_generator_set_actions_on_compare_event(generator,
                                                                 MCPWM_GEN_COMPARE_EVENT_ACTION(MCPWM_TIMER_DIRECTION_UP, comparator, MCPWM_GEN_ACTION_LOW),
                                                                 MCPWM_GEN_COMPARE_EVENT_ACTION_END()));

    ESP_LOGI(TAG, "Enable and start timer");
    ESP_ERROR_CHECK(mcpwm_timer_enable(servoObj->timer));
    ESP_ERROR_CHECK(mcpwm_timer_start_stop(servoObj->timer, MCPWM_TIMER_START_NO_STOP));
    servoObj->status = true;

    return comparator;
}

/**
 * @brief Get the step angle
 *
 * @param joyVal
 * @return double
 */
static double get_step_angle(uint16_t joyVal)
{

    if (joyVal == 0xffff)
    {
        joyVal -= 1;
    }
    int16_t val = joyVal - JOY_MID_VAL;
    int8_t sign = (val < 0) ? -1 : 1;

    double percent = (double)val / JOY_MID_VAL;
    if (fabs(percent) < JOY_DEAD_ZONE)
    { // 死区处理
        return 0;
    }

    double maxAngle = SERVO_MAX_SPEED * PROCESS_PERIOD;
    double anglePercent = (fabs(percent) - JOY_DEAD_ZONE) / (1 - JOY_DEAD_ZONE);
    anglePercent = pow(anglePercent, 5); // 摇杆小角度时缓慢变化，大角度时快速变化
    double step = anglePercent * maxAngle;

    return step * sign;
}
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

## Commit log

2023-04-07 守护者项目软件的初始版本，基于esp32 idf官方示例创建
2023-04-08 1、复制蓝牙HID进入项目目录 2、调整编译优化为-O2 3、调整flash spi0频率，cpu频率为最高
2023-04-08 基于ble_hid，添加了oeld显示
2023-04-08 添加舵机控制功能
2023-04-08 对mcpwm对象进行了一次简单抽象
2023-04-09 实现蓝牙手柄右摇杆控制头部转动和激光上下摆动
2023-04-15 添加瞄准时发出锁定音效功能
2023-05-28 适配OLED屏幕显示位置到眼睛位置
2023-05-28 重构舵机控制代码，抽出配置代码
2023-07-09 1、代码适配全新绘制pcb的管脚 2、新增电源控制模块 3、修改各任务优先级 4、修复xbox手柄字段结构体bug
    [i2s_std_sound.c, main.c, oled_drv.c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]
2023-07-09 1、新增led灯带模块 2、支持通过手柄十字键↑↓开关rgb灯带
2023-07-22 1、支持两路rgb灯带
2023-07-22 1、优化cmakelist，实现自动添加.c和include路径 2、修改配置，降低flash/cpu频率节省电量
2023-07-22 1、调整任务优先级 2、优化灯光颜色 3、新增舵机休眠功能，避免因度转造成的耗电
2023-07-23 1、新增状态机 2、新增FUNC0按键控制
2023-07-25 微调灯光颜色
2023-07-29 1、新增锂电池电压adc检测功能
2023-08-05 1、新增minimp3库，支持mp3播放 2、新增spiffs和分区表，支持从flash中读取文件
    [partitions.csv]
2023-08-07 1、状态机操作添加互斥锁 2、蓝牙hid数据增加重复事件过滤
2023-08-12 去除重复代码
2023-08-19 1、使能psram 2、新增minimp3_ex函数
2023-08-27 1、封装低内存和低延迟2个mp3播放接口 2、更新音频文件
2023-08-27 移除了pcm音频文件
2023-09-03 1、新增oled屏幕显示电量功能 2、新增部分
2023-09-03 2、新增部分音效
2023-09-03 一些微调
2023-09-24 1、添加眼部攻击动画 2、添加单色流转呼吸灯效果
2024-05-19 调整目录
    [partitions.csv]
2024-05-19 [model] 添加基础版本，当前版基于原型样机版本，修改了底座壁厚4mm-->3mm
    [18650_with_protector.SLDPRT, Li-ion_103450.SLDPRT, bevel_gear_25x1x12.SLDPRT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]
2024-05-19 [model] 修改头部细节，增强犄角灯光效果
    [head_corner.STL]
2024-05-19 [model] Add model directory and move the models to this repo
    [18650_with_protector.SLDPRT, Li-ion_103450.SLDPRT, bevel_gear_25x1x12.SLDPRT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]
2024-05-19 [pcb] Add the PCB of Guardian which is designed by Lceda.
2024-06-16 1.Referring to the attack mode of the Bow in Link's hands, the button layout for the Guardian's attack has been modified. Press the RT button to trigger the aiming attack, and you can press the B but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
2024-06-17 Add demo mod 1.you can use key_func0 or xbox button start to select demo mod. 2.The code has too many bugs because I uses too many global variables for inter-thread synchronization and uses too many 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
    [i2s_std_sound.c, main.c, oled_main.c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]
